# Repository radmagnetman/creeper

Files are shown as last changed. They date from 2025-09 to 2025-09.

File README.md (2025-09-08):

### Initial setup to program D1 Mini
Board manager -> download esp8266 board (tested with v3.1.2)
When ready to upload select com port and change board to "LOLIN(WEMOS) D1 R2 & mini"
Reference: https://www.airgradient.com/blog/basic-setup-skills-and-equipment-needed-to-build-our-airgradient-diy-sensor/

### D1 Mini Pinouts:
https://i0.wp.com/randomnerdtutorials.com/wp-content/uploads/2019/05/ESP8266-WeMos-D1-Mini-pinout-gpio-pin.png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

### Recommendation: 
Before soldering, load 'PT_Test_Tilt_Sensor.ino' onto D1 Mini to verify board operation. Periodically plug board in and monitor serial port to verify soldering hasn't damaged board.

Wiring

### Wiring
D1 Mini\
Solder the tilt sensor directly to board on D4 and D5 (GPIO 12 and 4). The sensor should be soldered to the opposite side of the wifi module and antenna.\
Test with tilt sensor code.\
Solder the following with dupont end wires on the same side as the tilt sensor
* 5V (+5V)
* G (Ground)
* A0 (Analog in)
* D1 (GPIO 6)

NeoPixel\
14 neo-pixels per strip. If different modify puck code.
Use plastic clamps to secure strip to wires. Use around 6" of appropriate gauge/color wire.

Buck converter\
Solder leads to board for all wires except Enable\
Wire battery compartment\
Before connecting to D1 MINI, Hook up battery to Buck converter (recommend aligator clamps). \
Use multimeter to measure voltage. Adjust with on-board pot to +5V.

Connect buck converter to positive of battery\
Connect buck converter output to positive on NeoPixel and +5V on D1 Mini

Knock sensor\
_Seperate from D1 Mini_\
1 Mohm resistor, bend leads to 90 deg at ~1 cm from resistor. \
Strip back wires on piezo element. Solder red and black wires to either side of 1 Mohm resistor. \
Solder ground and signal leads. \
Trim excess resistor wire. \
Use piece of tape wrap around resistor and all solder points, folding tape back on itself to cover all bare wires. Recommend gaffers tape. \
Solder signal wire to A0 on D1 Mini

There should be 5 ground connection: 
* battery
* *knock sensor
* NeoPixel
* Buck converter
* D1 Mini

Start grouping wires into pairs where possible, twisitng and soldering pairs together. \
Once down to three leads, connect all 3 with a Wago.

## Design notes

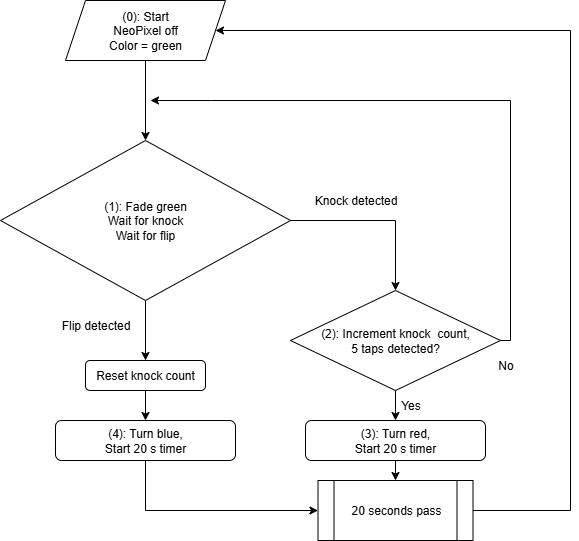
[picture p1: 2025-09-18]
Sprint 1b.drawio.png

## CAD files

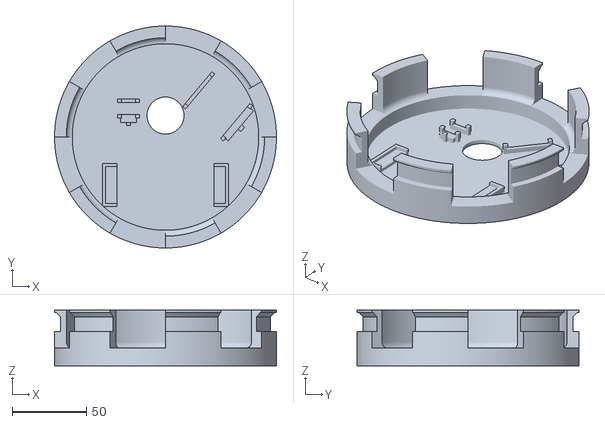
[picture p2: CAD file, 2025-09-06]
Electronics insert no brim v2.stl
150.0 x 150.0 x 37.5

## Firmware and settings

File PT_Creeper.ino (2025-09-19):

/*
  Creeper control v0.1
  This code base interfaces with an arduino-like microcontroller to ultimately
  control a string of neopixels. Attached to the arduino are the neo-pixels, 
  a knock sensor, and a tilt sensor. 
  This code was created for <redacted> to be used in <redacted>.

  Author: T. Wright
  Date: 8/31/2025
  Modified: 9/18/2025
*/
#include <Adafruit_NeoPixel.h>
#include <math.h>

/*
  The following declarations create the various state machines
  needed for operation
*/
// Stopped state, turn off neo-pixels
#define STOPPED 0
int operationState = STOPPED;
int prevOperationState = STOPPED+1;

// Turn on each neo-pixel in strip until all are on, then
// turn them off sequentially
#define RUNNING_UP 1
#define RUNNING_UP_OFF 0
#define RUNNING_UP_ON 1
int runningUpState = RUNNING_UP_OFF;

// Fade all neo-pixels on then off.
// fadeRateMultiplier changes the speed of the fade. Higher
//  means faster. 1 lets it run at the default rate (too slow imo)
#define RUNNING_FADE 2
#define RUNNING_FADE_IN 0
#define RUNNING_FADE_OUT 1
int runningFadeState = RUNNING_FADE_IN;
int fadeRateMultiplier = 5;

// Turn on all neo-pixels at once.
#define RUNNING_ALLON 3

// Game mode 1a
#define GAME_1A 4
#define GAME_1A_STEP_0 0
#define GAME_1A_STEP_1 1
#define GAME_1A_STEP_2 2
#define GAME_1A_STEP_3 3
#define GAME_1A_STEP_4 4
#define GAME_1A_STEP_5 5
int game1A_step = GAME_1A_STEP_0;

// Game mode 1b
#define GAME_1B 5
#define GAME_1B_STEP_0 0
#define GAME_1B_STEP_1 1
#define GAME_1B_STEP_2 2
#define GAME_1B_STEP_3 3
#define GAME_1B_STEP_4 4
int game1B_step = GAME_1B_STEP_0;
int knockInterval_ms = 1000;
int lastKnock_ms = 0;
bool fadeOn = true; // True meads fade on, false fade off
int knockCount = 0;
int game1B_knockThreshold = 5;
int game1B_redHold_ms = 16000;//20000;
int game1B_blueHold_ms = 20000;
int game1B_lastColorHold = 0;
bool game1B_flashState = false;
int game1B_flashTimes = 4;
int game1B_flashInterval_ms = 500;
int game1B_lastFlash = 0;

/* 
  Used to track when to do events. If microcontroller runs at 
  full speed, then events get skipped. This creates a 'heartbeat'
  for actions
*/
uint32_t time_ms = 0;
bool readyAction = false;
uint32_t globalDelay = 50; // in milliseconds, the 'heartbeat' of the device.

/* Knock sensor *************/
int knockSensor = A0;  // the piezo is connected to analog pin 0
int knockThreshold = 100;
uint32_t knockDebounce = 50;
uint32_t lastKnockRead = millis();
int knockReading = 0;
bool knockDetected = false;


/* Tilt sensor *************/
#define TILTSENSORPIN 14
#define TILTSENSORPINPOWER 12
bool currentDirection = false;
uint32_t lastTiltSwitch = millis();
uint32_t tiltDebounce = 500;
double tiltAverage = 0;
double lastTiltAverage = 0;
double tiltIintegrationSteps = 10;
bool tiltFlag = false;
bool lastTiltFlag = false;
bool flipped = false;

/* Define Neopixel *********/
#define LED_PIN    5
// How many NeoPixels are attached to the Arduino?
#define LED_COUNT 14
// Declare our NeoPixel strip object:
Adafruit_NeoPixel strip(LED_COUNT, LED_PIN, NEO_GRB + NEO_KHZ800);

// Neo-pixel predefined colors. For the strip in use, the colors are RGB
uint32_t red = strip.Color(255, 0, 0);
uint32_t green = strip.Color(0, 255, 0);
uint32_t blue = strip.Color(0, 0, 255);
uint32_t off = strip.Color(0, 0, 0);

uint32_t currentBrightness = 50; // Tracks current brightness value
uint32_t maxBrightness = 150; // 0-255, above 100 didn't see much difference
uint32_t currentPixelIndex = 0; // Used for sequential pixel actions
uint32_t currentPixelColor = off; //used to set global color
/***************************/

void setup() {

  operationState = GAME_1B;

  // init serial and timers
  Serial.begin(115200);
  delay(100);
  Serial.println("Starting creeper");
  time_ms = millis();
  delay(100);

  // set tilt sensor pin settings
  pinMode(TILTSENSORPIN,INPUT_PULLUP); // Sets tilt sensor pin read to high when not grounded
  
  pinMode(TILTSENSORPINPOWER,OUTPUT); // Set neighboring bin to ground
  digitalWrite(TILTSENSORPINPOWER,LOW);
    
  // Begin Neo-pixel
  strip.begin();           // INITIALIZE NeoPixel strip object (REQUIRED)
  strip.show();            // Turn OFF all pixels ASAP
  strip.setBrightness(currentBrightness); // Set BRIGHTNESS to about 1/5 (max = 255)
}

byte byte1 = 0;
byte byte2 = 0;
int lastStep =-1;

void loop() {
  // check timer to see if enough time has passed for action to happen
  if(millis()-time_ms > globalDelay) {
    time_ms = millis();
    readyAction = true;
  }
  else {readyAction = false;}

  // Output state to serial if there is a state change (used for debugging)
  if(prevOperationState != operationState) {
    Serial.print("State: ");Serial.println(operationState);
    prevOperationState = operationState;
  }

  if(millis()-lastTiltSwitch > tiltDebounce) {
    /*
      This if statement reads the titl sensor digital i/o pin. It performs
      a running average until the average values ttransitions between 0/1 states.
      To increase the time it takes to recognize a new value, increase 
      tiltIintegrationSteps variable in the declarations above.
      This routine also sets a global flag if tilt state changes.
    */
    currentDirection = digitalRead(TILTSENSORPIN);
    tiltAverage = lastTiltAverage * (tiltIintegrationSteps-1.0)/tiltIintegrationSteps + double(currentDirection)/tiltIintegrationSteps;
    lastTiltAverage = tiltAverage;
    
    if(round(tiltAverage) == 1) {tiltFlag = true;}
    else
    {tiltFlag = false;}

    if(lastTiltFlag != tiltFlag) {
      lastTiltFlag = tiltFlag;
      flipped = true;
      Serial.println("Flipped!");
    }
    
    lastTiltSwitch = millis();
  }

  // If enough time has passed to use knock sensor and the knock sensor reads above
  //  threshold, store knock value. 
  // Insert flags here for code that requires knock sensor reaction. 
  knockReading = analogRead(knockSensor);
  if((millis() - lastKnockRead > knockDebounce) && knockReading > 150){
    
    Serial.print("k: ");Serial.println(knockReading);
    lastKnockRead = millis();
    knockDetected = true;
  }

  /* 
    These commands can be hijacked for other uses such as a web interface. 
    Serial command set:
      's': Stop, all off neopiexl
      'r': Turn all on red
      'g': Turn all on green
      'b': Turn all on blue
      'ur','ug','ub': Turn on color, 1 by 1, then turn off, repeat
      'fr','fg','fb': Fade all on at specified color, then fade off
      'ga': Game mode 1a. Single knock on or off
      'gb': Game mode 1b. 
  */  
  byte1 = 0;
  byte2 = 0;

  bool found_g = false;

  if(Serial.available()) {
    byte1 = Serial.read();
    delay(50); // Normally delays not welcome, but successive read commands were getting skipped
    byte2 = Serial.read();
    while(Serial.available()){Serial.println("flush");Serial.read();} // flush buffer
    
    Serial.print("1: ");Serial.println((int) byte1);
    Serial.print("2: ");Serial.println((int) byte2);
    
    // if the second byte is new line character, then working with single character command
    if(byte2 == '\n') { 
      switch(byte1) {
        case 's': // received stop command
          operationState = STOPPED;
          break;
        case 'r': // Turn on all to red
          currentPixelColor = red;
          operationState = RUNNING_ALLON;
          break;
        case 'g': // Turn on all to green
          currentPixelColor = green;
          operationState = RUNNING_ALLON;
          break;
        case 'b': // Turn on all to blue
          currentPixelColor = blue;
          operationState = RUNNING_ALLON;
          break;
      }
    }
    else {
      switch(byte1) {
        case 'u': // Set state for sequential turning on of all LEDs. 
          operationState = RUNNING_UP;
          runningUpState = RUNNING_UP_ON;
          currentPixelIndex = 0; 
          break;
        case 'f': // Set state for fading pixels on and then off
          operationState = RUNNING_FADE;
          runningFadeState = RUNNING_FADE_IN;
          currentBrightness = 0;
          break;
        case 'g': // set state for waiting for knock.
          found_g = true;
      }

      // Set color of action defined in above switch statement
      switch(byte2) {
        case 'r':
          currentPixelColor = red;break;
        case 'g':
          currentPixelColor = green;break;
        case 'l':
          currentPixelColor = blue;break;
        case 'a':
          found_g = false;
          operationState = GAME_1A;
          game1A_step = GAME_1A_STEP_0;
          break;
        case 'b':
          found_g = false;
          operationState = GAME_1B;
          game1B_step = GAME_1B_STEP_0;
          break;
      }
    }
  }

  // STATE MACHINE
  // Using above commands, react to inputs.
  // Using readyAction to put everything on a global 'heartbeat'
  if(readyAction) {
    // Determine which state command was received from above.
    switch(operationState) {
      case STOPPED: // Turn off all pixels.
        strip.clear();
        strip.show();
        break;
      case RUNNING_UP: 
      // Turn on pixel to set color and brightness, increment index for next loop
      //  Using runningUpState to indicate whether turning on or off. When reached 0
      //  or max pixels, reset to zero and repeat with opposite state.
        if(runningUpState == RUNNING_UP_ON) { 
          currentPixelIndex++;
          strip.setPixelColor(currentPixelIndex,currentPixelColor);
          strip.show();

          if(currentPixelIndex > LED_COUNT) {
            runningUpState = RUNNING_UP_OFF;
            currentPixelIndex = 0;
          }
        }
        if(runningUpState == RUNNING_UP_OFF) {
          currentPixelIndex++;
          strip.setPixelColor(currentPixelIndex,off);
          strip.show();
          if(currentPixelIndex > LED_COUNT) {
            runningUpState = RUNNING_UP_ON;
            currentPixelIndex = 0;
          }
        }
        break;
      case RUNNING_FADE:
      // Set global brightess by increments of fadeRateMultiplier. Update all pixels
      // at the same time. When reach max brightness set fade direction downwards and 
      // subtract by multiplier. Repat sequence when bightness reaches zero.
        if(runningFadeState == RUNNING_FADE_IN) {
          currentBrightness += fadeRateMultiplier;
          if(currentBrightness > maxBrightness) {currentBrightness = maxBrightness;}
          strip.setBrightness(currentBrightness);
          if(currentBrightness == maxBrightness) {runningFadeState = RUNNING_FADE_OUT;}
        }
        if(runningFadeState == RUNNING_FADE_OUT) {
          currentBrightness -= fadeRateMultiplier;
          if(currentBrightness < 0) {currentBrightness = 0;}
          strip.setBrightness(currentBrightness);
          if(currentBrightness == 0) {runningFadeState = RUNNING_FADE_IN;}
        }
        strip.fill(currentPixelColor, 0, LED_COUNT);
        strip.show();
        break;
      case RUNNING_ALLON:
      // Turn on all pixels to the designated color.
        strip.fill(currentPixelColor, 0, LED_COUNT);
        strip.show();
        break;
      case GAME_1A:
        /*
          Steps for sprint 1a
          1 - Wait for knock, fade on green go to 2
          2 - Wait for knock, fade off green go to 1
              if 1 or 2 picks up knock, go to 3
          3 - Knock detected, turn off pixels go to 4
          4 - Knock detected, turn on pixels green
        */
        if(lastStep != game1A_step) {
          Serial.print("game_1A step: ");
          Serial.println(game1A_step);
          lastStep = game1A_step;
        }
        
        switch(game1A_step) {
          case GAME_1A_STEP_0:
            currentBrightness = 0;
            currentPixelColor = green;
            flipped = false;
            strip.clear();
            strip.show();
            game1A_step = GAME_1A_STEP_1;
            break;
          case GAME_1A_STEP_1:
            currentBrightness += fadeRateMultiplier;
            
            if(currentBrightness > maxBrightness) {
              currentBrightness = maxBrightness;
              game1A_step = GAME_1A_STEP_2;
            }
            strip.setBrightness(currentBrightness);
            strip.fill(currentPixelColor, 0, LED_COUNT);strip.show();
            if(knockDetected){game1A_step = GAME_1A_STEP_3;}
            break;
          case GAME_1A_STEP_2:
            currentBrightness -= fadeRateMultiplier;
            
            if(currentBrightness+fadeRateMultiplier < fadeRateMultiplier) {
              currentBrightness = 0;
              game1A_step = GAME_1A_STEP_1;
            }
            strip.setBrightness(currentBrightness);
            strip.fill(currentPixelColor, 0, LED_COUNT);strip.show();
            if(knockDetected){game1A_step = GAME_1A_STEP_3;}
            break;
          case GAME_1A_STEP_3:
            knockDetected = false;
            strip.clear();
            strip.show();
            Serial.println("Turning off pixels, knock detected");
            game1A_step = GAME_1A_STEP_4;
            break;
          case GAME_1A_STEP_4:
            if(knockDetected){
              knockDetected = false;
              game1A_step = GAME_1A_STEP_5;
              strip.setBrightness(maxBrightness);
              currentPixelColor = red;
              strip.fill(currentPixelColor, 0, LED_COUNT);strip.show();
              currentPixelColor = green;
            }
            if(tiltFlag) {game1A_step = GAME_1A_STEP_0;}
            break;
          case GAME_1A_STEP_5:
            if(knockDetected){
              knockDetected = false;
              game1A_step = GAME_1A_STEP_4;
              strip.clear();
              strip.show();
              currentPixelColor = green;
            }
            if(tiltFlag) {game1A_step = GAME_1A_STEP_0;}
            break;
        
        }
        break;
      case GAME_1B:
        knockThreshold = game1B_knockThreshold;
        if(lastStep != game1B_step) {
          Serial.print("game_1B step: ");
          Serial.println(game1B_step);
          lastStep = game1B_step;
        }
        
        
        switch(game1B_step) {
          case GAME_1B_STEP_0: // Start
            flipped = false;
            currentBrightness = 0;
            currentPixelColor = green;
            strip.fill(green, 0, LED_COUNT);
            strip.clear();
            strip.show();
            game1B_step = GAME_1B_STEP_1;
            currentPixelIndex = 0;
            knockDetected = false;
            break;
          case GAME_1B_STEP_1: // Fade green until knocked or flipped
            if(fadeOn) {currentBrightness += fadeRateMultiplier;}
            else {currentBrightness -= fadeRateMultiplier;}
            
            if(currentBrightness >= maxBrightness){currentBrightness = maxBrightness;fadeOn = false;}
            if(currentBrightness <= 0 || currentBrightness > 1000){currentBrightness = 0;fadeOn = true;}
            
            strip.setBrightness(currentBrightness);
            
            // Update pixel colors
            /*for(int i=0;i<LED_COUNT;i++){
              if(i < currentPixelIndex)
              {strip.setPixelColor(i,red);}
              else
              {strip.setPixelColor(i,green);}
            }*/
            switch(knockCount){
              case 0:
                for(int i=0;i<LED_COUNT;i++){strip.setPixelColor(i,green);}
                break;
              case 1: // 0, 5, 10
                strip.setPixelColor(0,red);
                strip.setPixelColor(1,green);
                strip.setPixelColor(2,green);
                strip.setPixelColor(3,green);
                strip.setPixelColor(4,green);
                strip.setPixelColor(5,red);
                strip.setPixelColor(6,green);
                strip.setPixelColor(7,green);
                strip.setPixelColor(8,green);
                strip.setPixelColor(9,green);
                strip.setPixelColor(10,red);
                strip.setPixelColor(11,green);
                strip.setPixelColor(12,green);
                strip.setPixelColor(13,green);
                break;
              case 2: //1,6,11
                strip.setPixelColor(0,red);
                strip.setPixelColor(1,red);
                strip.setPixelColor(2,green);
                strip.setPixelColor(3,green);
                strip.setPixelColor(4,green);
                strip.setPixelColor(5,red);
                strip.setPixelColor(6,red);
                strip.setPixelColor(7,green);
                strip.setPixelColor(8,green);
                strip.setPixelColor(9,green);
                strip.setPixelColor(10,red);
                strip.setPixelColor(11,red);
                strip.setPixelColor(12,green);
                strip.setPixelColor(13,green);
                break;
              case 3: //2,7,12
                strip.setPixelColor(0,red);
                strip.setPixelColor(1,red);
                strip.setPixelColor(2,red);
                strip.setPixelColor(3,green);
                strip.setPixelColor(4,green);
                strip.setPixelColor(5,red);
                strip.setPixelColor(6,red);
                strip.setPixelColor(7,red);
                strip.setPixelColor(8,green);
                strip.setPixelColor(9,green);
                strip.setPixelColor(10,red);
                strip.setPixelColor(11,red);
                strip.setPixelColor(12,red);
                strip.setPixelColor(13,green);

                break;
              case 4://3,8,13
                strip.setPixelColor(0,red);
                strip.setPixelColor(1,red);
                strip.setPixelColor(2,red);
                strip.setPixelColor(3,red);
                strip.setPixelColor(4,green);
                strip.setPixelColor(5,red);
                strip.setPixelColor(6,red);
                strip.setPixelColor(7,red);
                strip.setPixelColor(8,red);
                strip.setPixelColor(9,green);
                strip.setPixelColor(10,red);
                strip.setPixelColor(11,red);
                strip.setPixelColor(12,red);
                strip.setPixelColor(13,red);
                break;
              case 5: //4,9
                strip.setPixelColor(0,red);
                strip.setPixelColor(1,red);
                strip.setPixelColor(2,red);
                strip.setPixelColor(3,red);
                strip.setPixelColor(4,red);
                strip.setPixelColor(5,red);
                strip.setPixelColor(6,red);
                strip.setPixelColor(7,red);
                strip.setPixelColor(8,red);
                strip.setPixelColor(9,red);
                strip.setPixelColor(10,red);
                strip.setPixelColor(11,red);
                strip.setPixelColor(12,red);
                strip.setPixelColor(13,red);
                break;

            }
            strip.show();

            // When knock detect, increment knock count and check against threshold. 
            //  Also, change 3 pixels from green to red. 
            // When threshold reached, reset values, go to waiting
            if(knockDetected && ((millis() - lastKnock_ms) > knockInterval_ms)){
              knockDetected = false;
              lastKnock_ms = millis();
              knockCount++;
              currentPixelIndex = currentPixelIndex+3;
              
              if(knockCount >= knockThreshold) {
                knockCount = 0;
                game1B_step = GAME_1B_STEP_4;
                game1B_lastColorHold = millis();
                currentBrightness = maxBrightness;
                currentPixelColor = red;
                strip.fill(currentPixelColor, 0, LED_COUNT);
                strip.show();            
              }
            }
            
            // If the creeper is detected to be flipped via code in above, set blue
            //  and go to wait state
            if(flipped) {
              game1B_step = GAME_1B_STEP_3;
              game1B_lastColorHold = millis();
              knockCount = 0;
              currentBrightness = maxBrightness;
              currentPixelColor = blue;
              strip.fill(currentPixelColor, 0, LED_COUNT);
              strip.show();            
            }

            break;
          case GAME_1B_STEP_2: // wait for red time out
            if(millis() - game1B_lastColorHold > game1B_redHold_ms) {
              game1B_step = GAME_1B_STEP_0;
            }
            break;
          case GAME_1B_STEP_3: // wait for blue time out
            if(millis() - game1B_lastColorHold > game1B_blueHold_ms) {
              game1B_step = GAME_1B_STEP_0;
            }
            break;
          case GAME_1B_STEP_4: // unused
              //bool game1B_flashState = false;
              //int game1B_flashTimes = 3;
              //int game1B_flashInterval_ms = 500;
              currentPixelColor = red;
              if((millis() - game1B_lastFlash) > game1B_flashInterval_ms){
                game1B_lastFlash = millis();
                if(game1B_flashState) {
                  strip.fill(currentPixelColor, 0, LED_COUNT);
                  game1B_flashState = false;
                }
                else {
                  game1B_flashTimes--;
                  strip.fill(off, 0, LED_COUNT);
                  game1B_flashState = true;
                }
              }
            
            if(game1B_flashTimes == 0) {
              game1B_step = GAME_1B_STEP_2;
              game1B_flashTimes = 3;
              strip.fill(currentPixelColor, 0, LED_COUNT);
            }
            strip.show();
            break;

        }
        break;
    }
  }

}

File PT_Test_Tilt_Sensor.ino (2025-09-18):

/*
#define TILTSENSORPIN 14  // D5 on D1 Mini
#define TILTSENSORPINPOWER 12 // D6 on D1 Mini
bool currentDirection = false;

void setup() {
  Serial.begin(115200);
  Serial.println("Starting...");
  
  pinMode(TILTSENSORPIN,INPUT_PULLUP); // Turn on pullup resistor so that it goes high when NC
  
  pinMode(TILTSENSORPINPOWER,OUTPUT); // Set nearby pin to low to get as a close by ground for
  digitalWrite(TILTSENSORPINPOWER,LOW); // tilt sensor

}

void loop() {
  currentDirection = digitalRead(TILTSENSORPIN); // Read digitial I/O pin

  Serial.print(currentDirection);Serial.print(" ");

  if(currentDirection) 
  {Serial.println("down");}
  else
  {Serial.println("up");}
  
  delay(1000);
}
*/

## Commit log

2025-08-31 Initial upload of arduino file.
2025-09-06 Updated ino. Added STL
    [Electronics insert no brim v2.stl]
